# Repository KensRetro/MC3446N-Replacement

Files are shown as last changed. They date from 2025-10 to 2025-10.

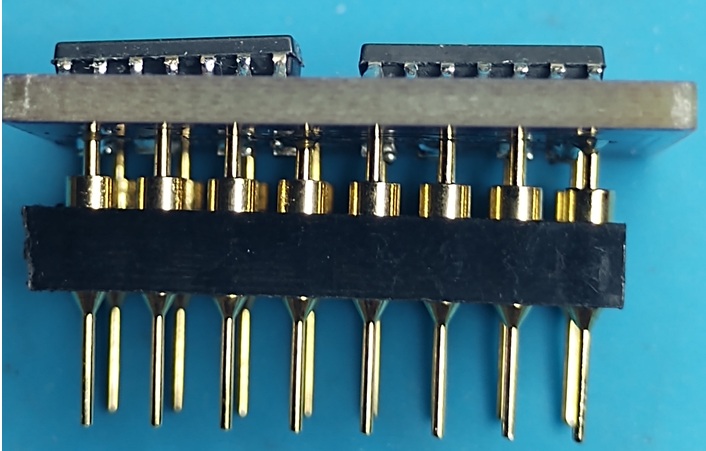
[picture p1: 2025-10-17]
Pictures/PIX3.jpg

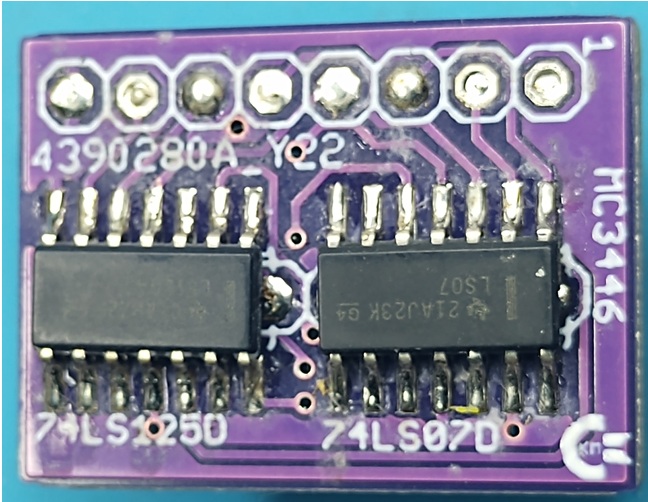
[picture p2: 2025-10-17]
Pictures/PIX2.jpg

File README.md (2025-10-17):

A replacement for the no longer manufactured MC3446 IC.  Not exactly the same spec but unless you are loading it down with many connections you'll never notice.

The module is simple and most of the time fits right into the socket if there's enough clearance.
The circuit mimics the internals of the original chip and has been tested in a PET computer with great success.

Very few parts needed to assemble the board.  It is recommended to mount the board at the TOP of the pins (or shear off the pins) so the 
surface mount components will sit correctly.  Minimal surface mount soldering is needed, a little care and patience goes a long way.

DISCLAIMER: All information is provided 'AS-IS" for informational purposes only. I have tried to be as accurate as possible but that doesn't mean there are no mistakes. Any errors or omissions etc. are your own responsibility.
There is no Warranty or guarantee of any kind. See licence for details.

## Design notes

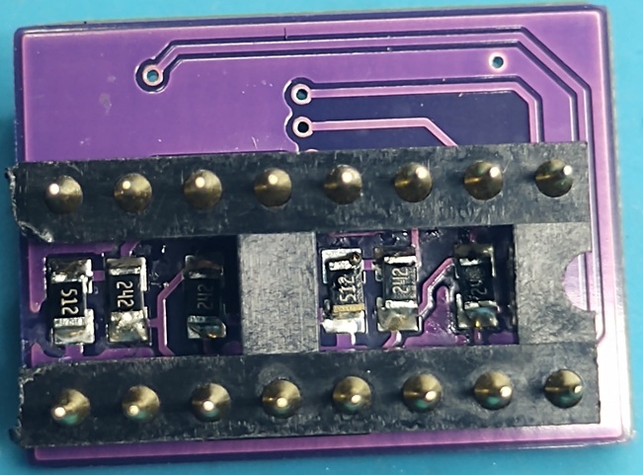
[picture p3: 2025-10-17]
Pictures/PIX1.jpg

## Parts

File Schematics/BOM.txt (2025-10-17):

Qty Value    Device     Parts                                                 
16           PINHD-1X1  +5V, 1, 2, 3, 4, 5, 6, 7, 8, 9, 10, 11, 12, 13, 14, 15
4   2.4k     R-US_R0805 R1, R3, R6, R8                                        
4   5.1k     R-US_R0805 R2, R4, R5, R7                                        
1   74LS07D  74LS07D    IC2                                                   
1   74LS125D 74LS125D   IC1

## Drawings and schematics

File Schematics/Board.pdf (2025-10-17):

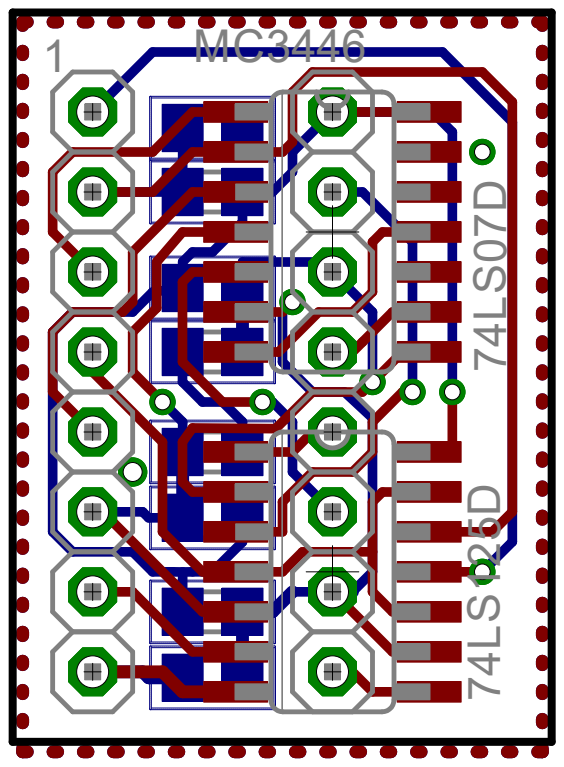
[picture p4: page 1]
74LS¹²⁵D ⁷⁴LS⁰⁷D

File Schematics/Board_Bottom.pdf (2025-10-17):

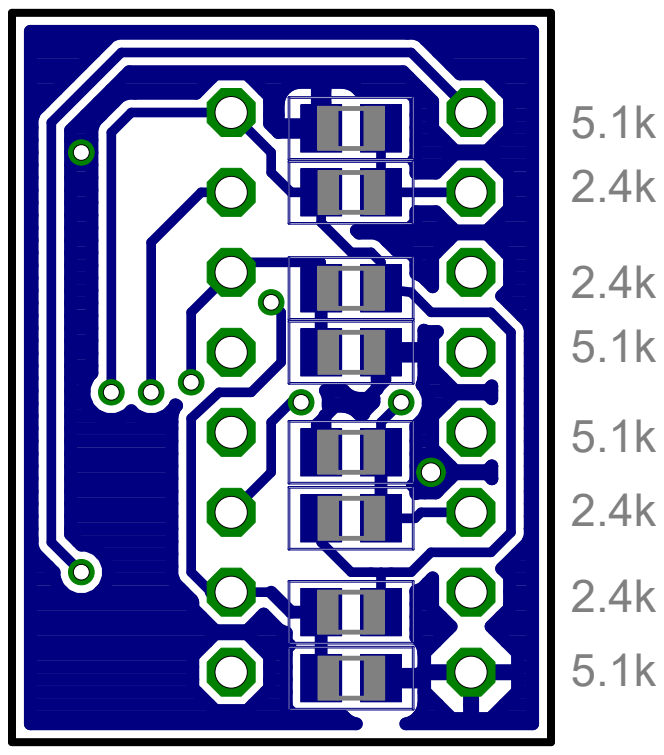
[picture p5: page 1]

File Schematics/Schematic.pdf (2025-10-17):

# 74LS125D 74LS⁰⁷D 74LS⁰⁷D 74LS⁰⁷D 74LS⁰⁷D

# IC1C¹³

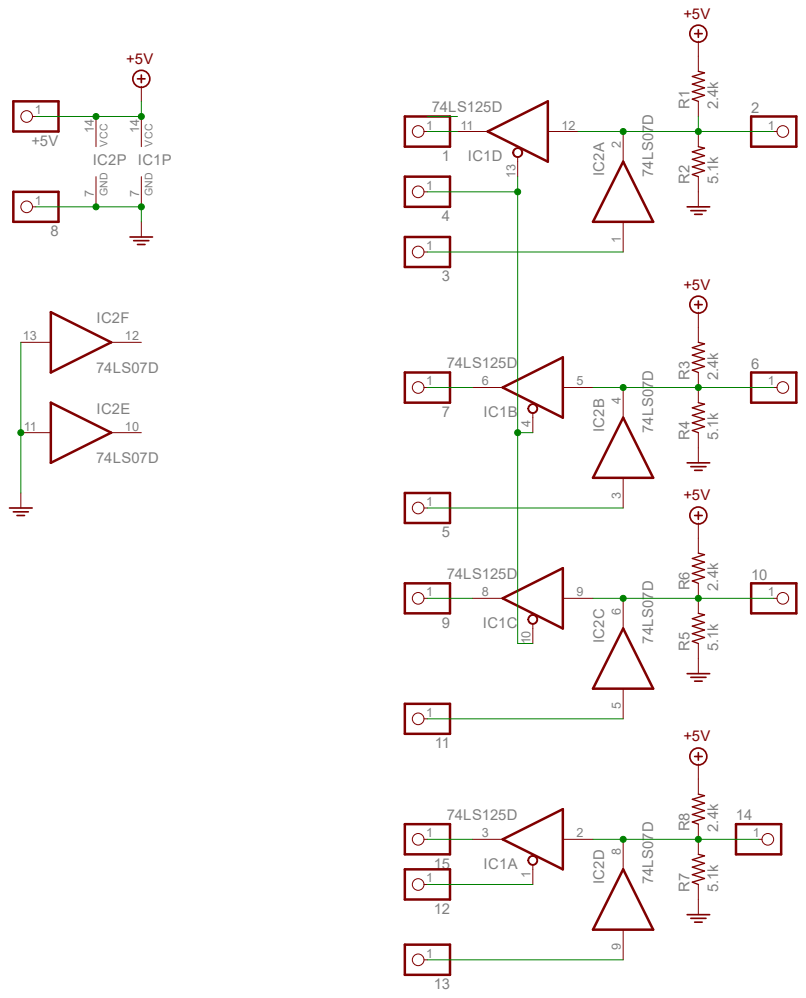
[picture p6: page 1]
IC1D 7 14 IC1PGND VCC; 1 2 IC²A 3 4 IC²B 5 6 IC²C 9 8 IC²D; IC2F ⁷ ¹⁴ IC2PGND VCC

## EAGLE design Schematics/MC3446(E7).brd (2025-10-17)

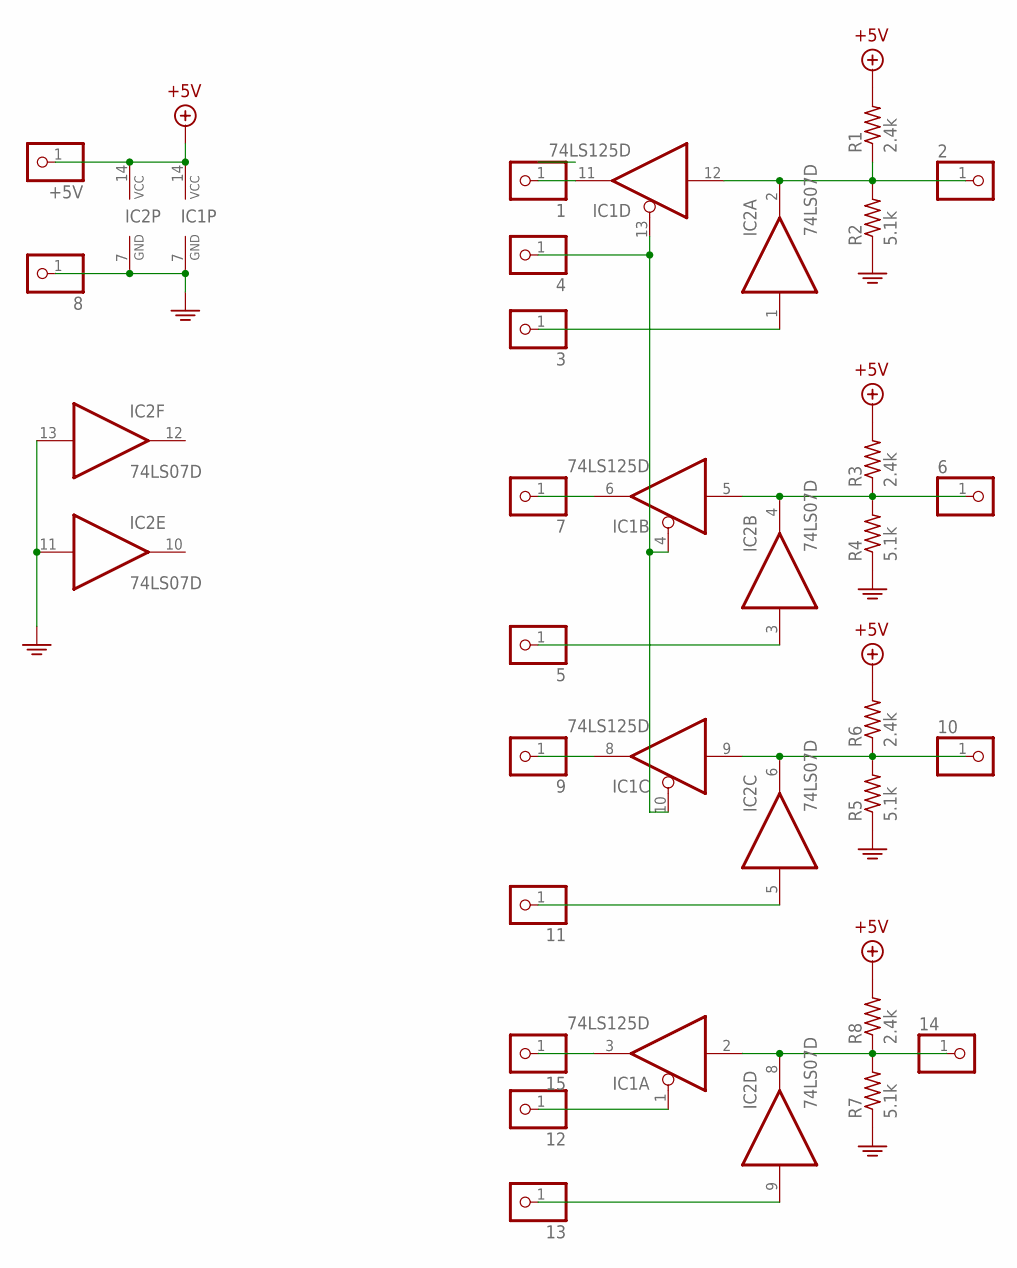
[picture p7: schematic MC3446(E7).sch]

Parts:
1, 2, 3, 4, 5, 6, 7, 8, 9, 10, 11, 12, 13, 14, 15: PINHD-1X1; 1X01
+5V: PINHD-1X1; 1X01
IC1: 74LS125D; SO14
IC2: 74LS07D; SO14
R1, R3, R6, R8: 2.4k; R0805
R2, R4, R5, R7: 5.1k; R0805

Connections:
+5V: +5V.1, IC1.14 (VCC), IC2.14 (VCC), R1.2, R3.2, R6.2, R8.2
GND: 8.1, IC1.7 (GND), IC2.7 (GND), IC2.11 (I), IC2.13 (I), R2.1, R4.1, R5.1, R7.1
unnamed: 2.1, IC1.12 (I), IC2.2 (O), R1.1, R2.2
unnamed: 3.1, IC2.1 (I)
unnamed: 1.1, IC1.11 (O)
unnamed: 4.1, IC1.4 (OE), IC1.10 (OE), IC1.13 (OE)
unnamed: 6.1, IC1.5 (I), IC2.4 (O), R3.1, R4.2
unnamed: 10.1, IC1.9 (I), IC2.6 (O), R5.2, R6.1
unnamed: 14.1, IC1.2 (I), IC2.8 (O), R7.2, R8.1
unnamed: 7.1, IC1.6 (O)
unnamed: 5.1, IC2.3 (I)
unnamed: 9.1, IC1.8 (O)
unnamed: 15.1, IC1.3 (O)
unnamed: 11.1, IC2.5 (I)
unnamed: 13.1, IC2.9 (I)
unnamed: 12.1, IC1.1 (OE)

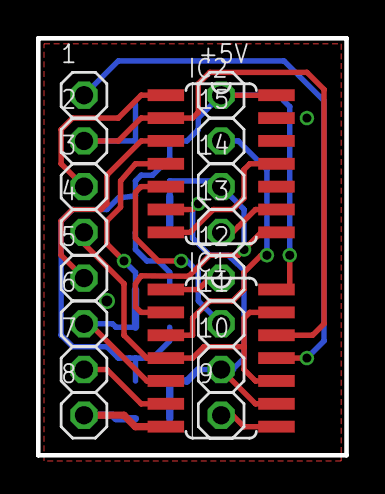
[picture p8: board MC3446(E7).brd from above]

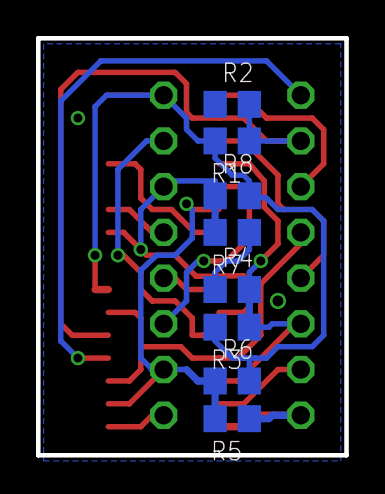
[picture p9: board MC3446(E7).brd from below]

Board: 2 copper layers, 17.1 x 23.2 mm, 26 parts (8 on the bottom side), 16 nets.
